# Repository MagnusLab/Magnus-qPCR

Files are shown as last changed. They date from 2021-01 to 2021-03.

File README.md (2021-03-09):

# 
An open, portable and low cost qPCR machine.

## WE ARE ACCEPTING [DONATIONS](https://www.vakinha.com.br/vaquinha/nos-ajude-a-desenvolver-uma-maquina-de-qpcr-a-baixo-custo)!: 

## Specifications*:
* 8 samples
* 1 to 4 channels, you can customize it!
  * FAM/Sybr Green
  * HEX
  * ROX/Cal Red 610
  * Cy5
* MicroSD card slot for data logging
* High Resolution Melting Analysis
* WiFi interface, so you can control and visualize data from a smartphone/PC
* Portable (less than 150 mm in size)
* USB powered (5V 3A power supply)
* CHEAP

**This machine is a work in progress, so the specifications may change and/or be innacurate. Also, don't try to replicate it if you don't know what you're doing, as it probably won't work until we release a stable version.*

## How will it work?
The machine can be roughly separated into 3 parts:

* The main PCB, containing the microcontroller and the heater;
* The PCB of the reading head, containing LEDs and light sensors;
* The optical reading head, which will house lenses, beam splitters, filters, prisms, etc., as well as the stepper motor responsible for positioning this optical assembly above each tube;


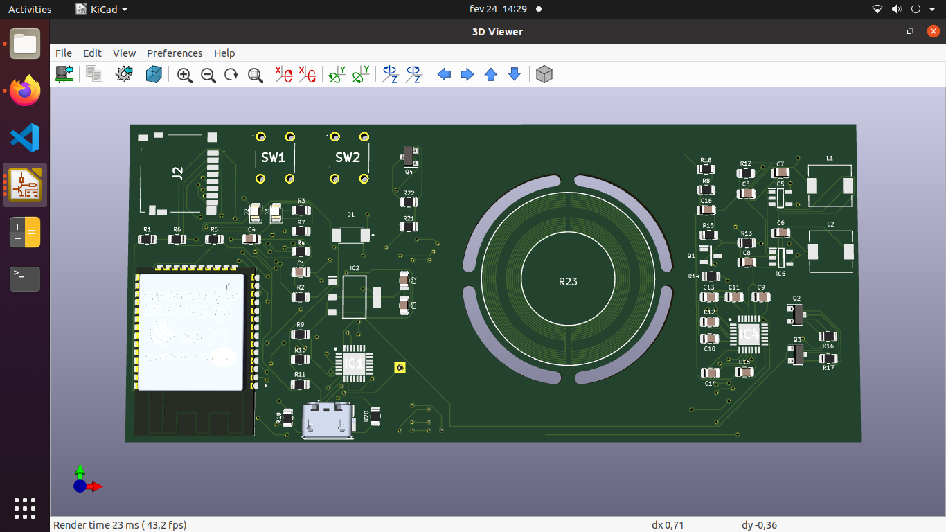
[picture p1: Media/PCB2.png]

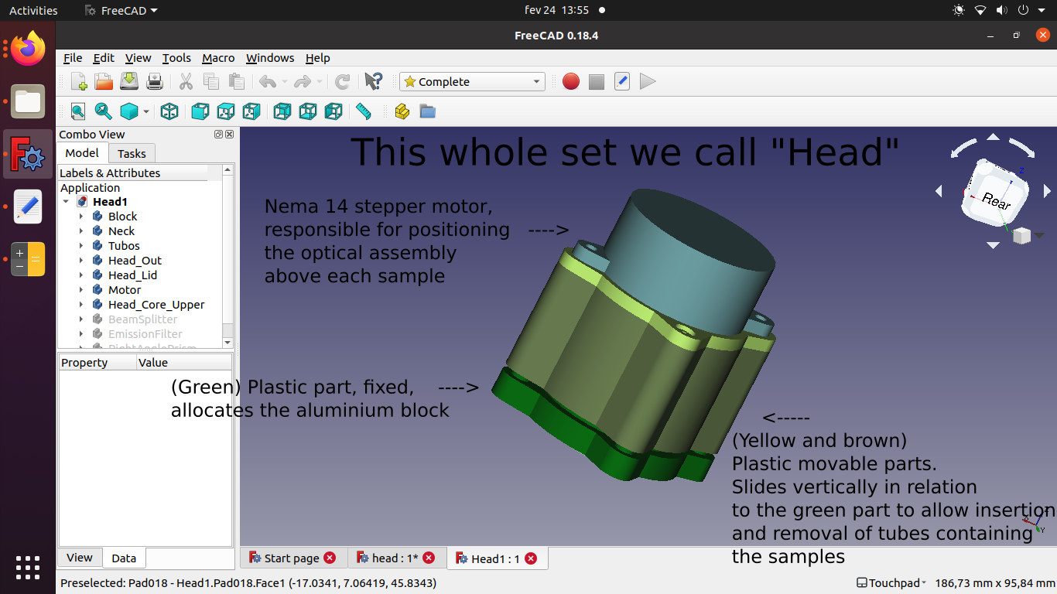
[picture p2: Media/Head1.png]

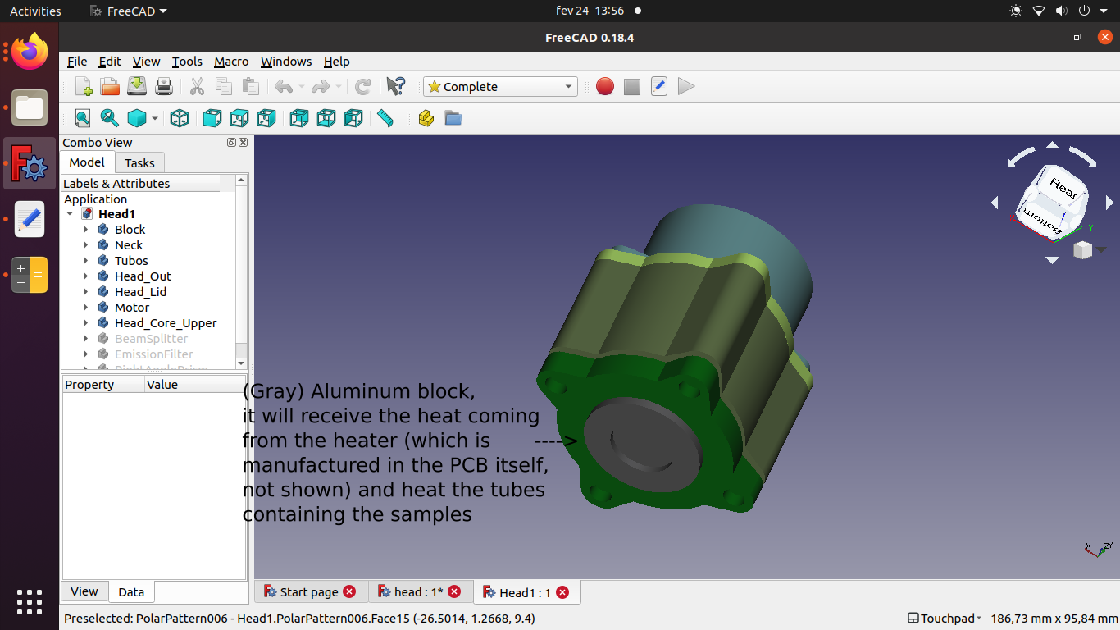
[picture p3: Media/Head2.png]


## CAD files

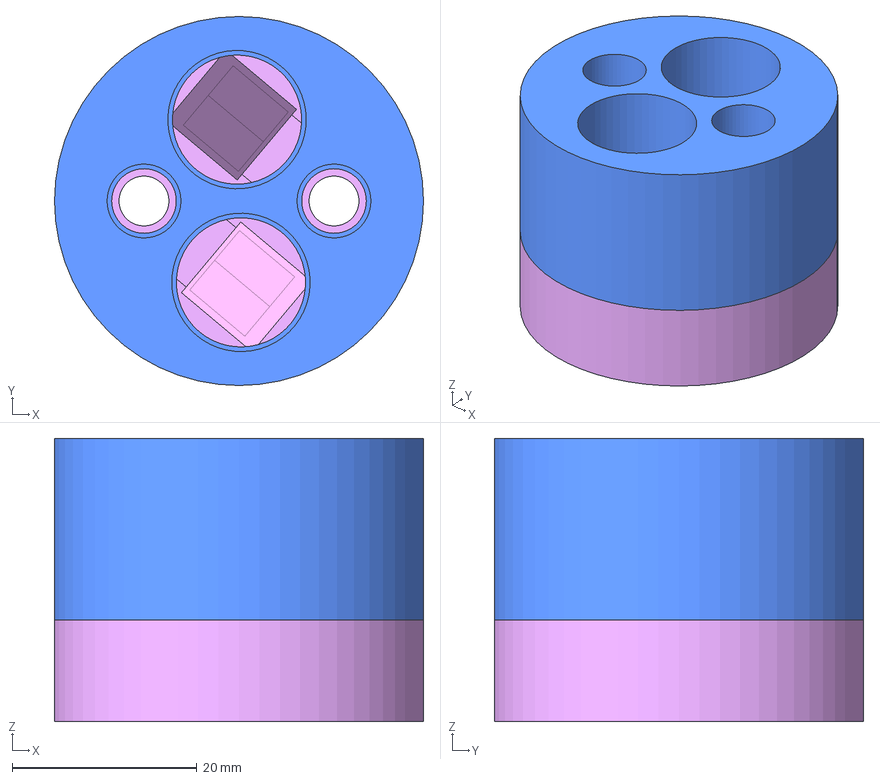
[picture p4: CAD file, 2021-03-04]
Hardware/FreeCAD/head.FCStd
40.0 x 40.0 x 30.7 mm
Head_Core_Bottom
Head_Core_Top

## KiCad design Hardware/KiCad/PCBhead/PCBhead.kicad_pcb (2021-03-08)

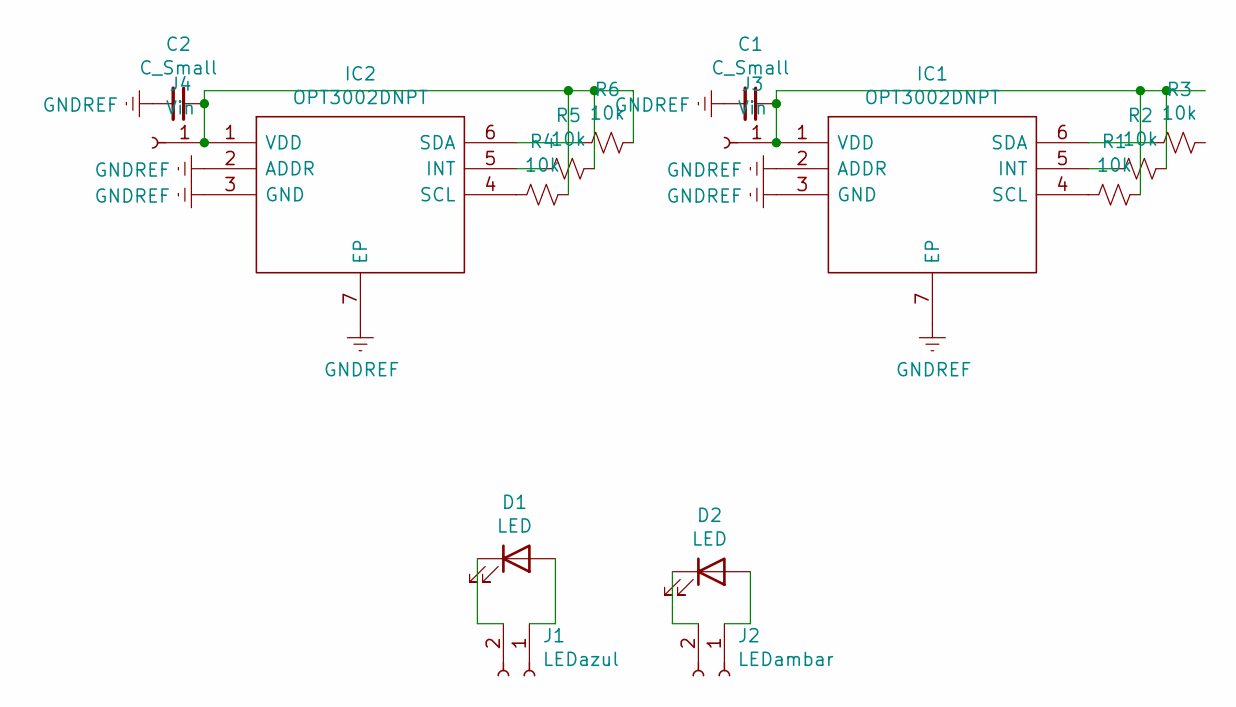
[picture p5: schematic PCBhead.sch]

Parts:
C1, C2: C_Small; C_0805_2012Metric
D1, D2: LED
IC1, IC2: OPT3002DNPT; SON65P200X200X65-7N-D; Mouser Part Number 595-OPT3002DNPT
J1: LEDazul; PinSocket_1x02_P2.54mm_Horizontal
J2: LEDambar; PinSocket_1x02_P2.54mm_Horizontal
J3, J4: Vin; PinSocket_1x01_P2.54mm_Horizontal
R1, R2, R3, R4, R5, R6: 10k; R_0805_2012Metric

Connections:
GNDREF: C1.2, C2.2, IC1.2 (ADDR), IC1.3 (GND), IC1.7 (EP), IC2.2 (ADDR), IC2.3 (GND), IC2.7 (EP)
unnamed: C1.1, IC1.1 (VDD), J3.1, R1.1, R2.1
unnamed: C2.1, IC2.1 (VDD), J4.1, R4.1, R5.1, R6.1
unnamed: D1.1 (K), J1.2
unnamed: D1.2 (A), J1.1
unnamed: D2.1 (K), J2.2
unnamed: D2.2 (A), J2.1
unnamed: IC1.4 (SCL), R1.2
unnamed: IC1.5 (INT), R2.2
unnamed: IC1.6 (SDA), R3.2
unnamed: IC2.4 (SCL), R4.2
unnamed: IC2.5 (INT), R5.2
unnamed: IC2.6 (SDA), R6.2

Board: 2 copper layers, 16 parts (12 on the bottom side), 13 nets, no tracks yet.

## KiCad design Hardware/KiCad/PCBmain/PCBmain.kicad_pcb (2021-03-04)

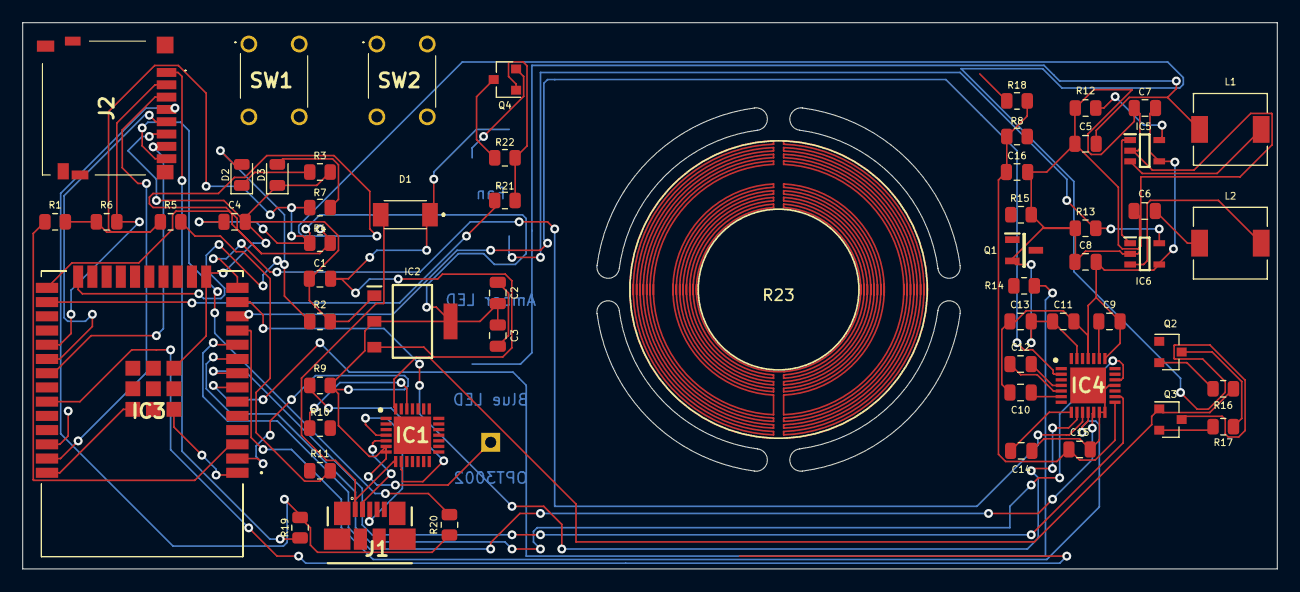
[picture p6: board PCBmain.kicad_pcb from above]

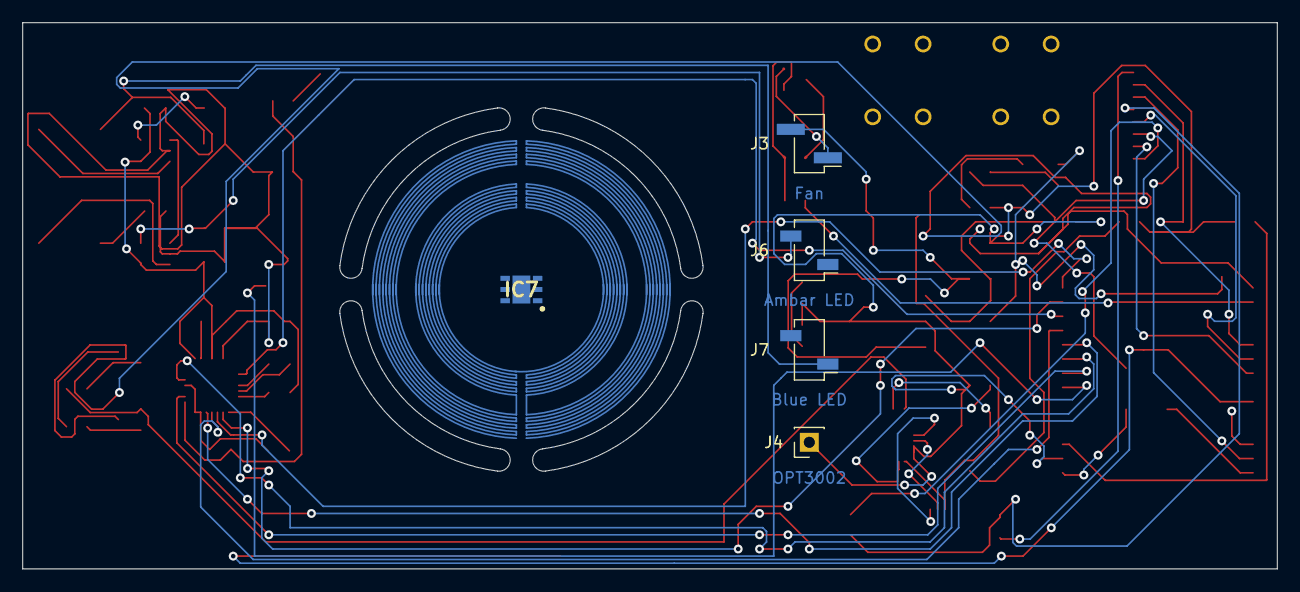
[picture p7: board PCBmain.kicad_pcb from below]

Board: 2 copper layers, 112.0 x 48.8 mm, 63 parts (5 on the bottom side), 53 nets.

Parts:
C1, C3, C5, C6, C7, C8: 10µF; C_0805_2012Metric
C2, C11, C13, C15: 100nF; C_0805_2012Metric
C4: 100µF 6.3V; C_0805_2012Metric
C9: 100µF; C_0805_2012Metric
C10: 22nF 50V; C_0805_2012Metric
C12: 100nF 16V; C_0805_2012Metric
C14: 2.2µF 6.3V; C_0805_2012Metric
C16: 0.1µF; C_0805_2012Metric
D1: D_Schottky_Small; PMEG3050EP115
D2, D3: LED; LED_0805_2012Metric
IC1: CP2102; QFN50P500X500X100-29N-D
IC2: NCP1117ST33T3G; SOT230P700X180-4N
IC3: ESP32-WROOM-32_M103QH3200PH3Q0_; ESP32WROOM32M103QH3200PH3Q0
IC4: TMC2208-LA-T; QFN50P500X500X90-29N-D
IC5, IC6: PAM2804AAB010; SOT95P280X100-5N
IC7: TMP117AIDRVT; SON100P300X300X80-7N-D
J1: 47346-0001
J2: DM3D-SF; DM3DSF
J3: fan; PinHeader_1x02_P2.54mm_Vertical_SMD_Pin1Left
J4: OPT3002; PinSocket_1x01_P2.54mm_Vertical
J6: LEDambar; PinSocket_1x02_P2.54mm_Vertical_SMD_Pin1Left
J7: LEDazul; PinSocket_1x02_P2.54mm_Vertical_SMD_Pin1Left
L1, L2: 4,7µH; L_6.3x6.3_H3
Q1: IRLML6244TRPBF; SOT95P237X112-3N
Q2, Q3: S8050; SOT-23
Q4: Q_NMOS_GDS; SOT-23
R1, R2, R4, R5, R6, R8, R15, R16, R17, R18, R19, R20, R22: 10k; R_0805_2012Metric
R3, R7, R10, R11: 1k; R_0805_2012Metric
R9: 4.7k; R_0805_2012Metric
R12, R13: ?; R_0805_2012Metric
R14, R21: 200; R_0805_2012Metric
R23: Heater; aquecedor
SW1, SW2: SW_Push; TS665CJ

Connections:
/3.3V: J2.4, R19.2, R20.1
/CLK: IC3.30, J2.5
/CMD: IC3.37, J2.3
/D+: IC1.4, J1.3
/D-: IC1.5, J1.2
/DAT0: IC3.31, J2.7
/DIAG: IC3.11, IC4.11
/DIR: IC3.9, IC4.19
/DTR: IC1.28, Q3.1, R16.1
/EN: IC3.3, Q2.1, R1.1
/ENN: IC3.12, IC4.2
/GPIO0: IC3.25, Q3.3, R4.2
/GPIO2: D2.2, IC3.24, R2.1
/GPIO5: IC3.29, J2.2, R6.2
/INDEX: IC3.10, IC4.12
/LEDamar+: C6.2, L2.1
/LEDambar-: IC6.5, J6.2, R13.2
/LEDazul+: C5.2, J7.1, L1.1
/LEDazul-: IC5.5, J7.2, R12.2
/MS1: IC3.13, IC4.9
/MS2: IC3.14, IC4.10
/Mosfet: Q1.3, R23.2
/PWMaquecedor: IC3.7, R14.2
/PWMled: IC3.6, IC5.1, IC6.1
/RTS: IC1.24, Q2.3, R17.1
/SCL: IC3.36, IC7.1, R8.2
/SDA: IC3.33, IC7.6, R18.2
/STEP: IC3.8, IC4.16
/TX0: R5.2, R11.2
/VCC_USB: D1.2, IC1.8, J1.1
/VDD_3.3V: C2.2, C3.1, C4.1, C15.1, C16.1, IC1.6, IC1.7, IC2.2, IC2.4, IC3.2, IC4.15, IC7.5, J4.1, R1.2, R4.1, R5.1, R6.1, R7.1, R8.1, R9.2, R18.1
/Vin: C1.1, C7.2, C8.2, C9.1, C10.2, C11.2, C13.2, D1.1, IC2.3, IC4.22, IC4.25, IC5.4, IC6.4, J3.2, R23.1
/fan: IC3.26, R21.1
/stepperMotor: IC4.1, IC4.21, IC4.24, IC4.26
GNDREF: C1.2, C2.1, C3.2, C4.2, C5.1, C6.1, C7.1, C8.1, C9.2, C11.1, C13.1, C14.1, C15.2, C16.2, D3.1, IC2.1, IC3.1, IC3.15, IC3.38, IC3.39, IC3.40, IC3.41, IC3.42, IC3.43, IC3.44, IC3.45, IC3.46, IC3.47, IC4.3, IC4.13, IC4.14, IC4.18, IC4.23, IC4.27, IC4.29, IC5.2, IC6.2, IC7.2, J1.5, J2.6, Q1.2, Q4.3, R2.2, R3.2, R12.1, R13.1, R15.1, R22.1
unnamed: C10.1, IC4.6
unnamed: C12.1, IC4.5
unnamed: C12.2, IC4.4
unnamed: C14.2, IC4.8
unnamed: D2.1, R3.1
unnamed: D3.2, R7.2
unnamed: IC1.9, R9.1
unnamed: IC1.25, R11.1
unnamed: IC1.26, R10.1
unnamed: IC5.3, L1.2
unnamed: IC6.3, L2.2
unnamed: J2.1, R19.1
unnamed: J2.8, R20.2
unnamed: J3.1, Q4.2
unnamed: Q1.1, R14.1, R15.2
unnamed: Q2.2, R16.2
unnamed: Q3.2, R17.2
unnamed: Q4.1, R21.2, R22.2

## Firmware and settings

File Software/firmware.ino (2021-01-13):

#include <Servo.h>

#include "esp_task_wdt.h"
#include <ArduinoJson.h>
//
#include <stdio.h>
#include <stdlib.h>
#include <SPI.h>
#include <FS.h>
#include "SPIFFS.h"
//
#include <WiFi.h>
#include "time.h"
#include <WiFiClient.h>
#include <WebServer.h>
#include <ESPmDNS.h>

WebServer server(80);
//
const unsigned int pinThermVcc = 25;
const unsigned int pinThermADC = 35;
const unsigned int pinTSL235RVcc = 12;
const unsigned int pinTSL235Rdata = 34;
const unsigned int pinServo = 32;
const unsigned int pinHeater = 33;
const unsigned int pinFan = 13;

const unsigned int ledR = 14;
const unsigned int ledG = 27;
const unsigned int ledB = 26;
const unsigned int led2 = 2;

const unsigned int ThermR0 = 100000;
const int ThermTemp0 = 25;
const unsigned int ThermBeta = 3950;
const unsigned int ThermRSeries = 100000;

const char* ssid     = "Benicio";
const char* password = "989666195";

const char* ntpServer = "pool.ntp.org";
const long  gmtOffset_sec = -3 * 3600;
const int   daylightOffset_sec = 0;

#define FORMAT_SPIFFS_IF_FAILED true

TaskHandle_t Task0;

struct DataLog {
  int tempWell;
  unsigned long time_;
  float data_;
};

void writeFile(fs::FS &fs, const char * path, const char * message);
int readIntFromFile(const char *path);
void appendFile(fs::FS &fs, const char * path, const char * message);
void deleteFile(fs::FS &fs, const char * path);

class CycleStepper {
    const char* _json = "[{\"iterations\":1,\"cycle\":[{\"temp\":95,\"duration\":15,\"fluorRead\":false}]},{\"iterations\":5,\"cycle\":[{\"temp\":95,\"duration\":3,\"fluorRead\":false},{\"temp\":56,\"duration\":30,\"fluorRead\":true}]}]";
    const char* _cycleJson; // = "[{\"iterations\":1,\"cycle\":[{\"temp\":37,\"duration\":60,\"fluorRead\":false},{\"temp\":31,\"duration\":18,\"fluorRead\":true}]},{\"iterations\":1,\"cycle\":[{\"temp\":95,\"duration\":30,\"fluorRead\":false},{\"temp\":60,\"duration\":30,\"fluorRead\":false},{\"iterations\":2,\"cycle\":[{\"temp\":20,\"duration\":10,\"fluorRead\":false},{\"temp\":22,\"duration\":5,\"fluorRead\":false}]},{\"iterations\":2,\"cycle\":[{\"temp\":72,\"duration\":30,\"fluorRead\":true}]}]},{\"iterations\":2,\"cycle\":[{\"temp\":4,\"duration\":0}]}]";
    enum States {ZERO, TEST_END_REACHED, TEMP_OR_HEADER, TEMP, HEADER} state = ZERO;
    static const unsigned int MAX_SIZE_STATES = 16;
    struct StatesVariables {
      int iterations;
      int index;
    } statesVars[MAX_SIZE_STATES];
    int statesVarsCount;
    struct CurrentCycle {
      float temp;
      float duration;
      bool readFluor;
    } currentCycle;

  public:
    void init(const char* cycleJson) {
      Serial.printf("CycleStepper::init started on core %d\n", xPortGetCoreID());
      char *cycleJson_;
      cycleJson_ = (char*)malloc(strlen(cycleJson)+1);
      strncpy(cycleJson_, cycleJson, strlen(cycleJson)+1);
      _cycleJson = (const char*)cycleJson_;
      Serial.printf("Cyclestepper::init, _cycleJson = %s\n", _cycleJson);
    }
    void getCurrentCycle(float* temp, float* duration, bool*readFluor) {
      *temp = currentCycle.temp;
      *duration = currentCycle.duration;
      *readFluor = currentCycle.readFluor;
    }
    bool nextStep() {
      while (true) {
        DynamicJsonDocument doc(ESP.getMaxAllocHeap());
        doc.clear();
        deserializeJson(doc, _json);
        doc.shrinkToFit();
        Serial.printf("Cyclestepper::nextStep, _cycleJson = %s\n", (const char*)_cycleJson);
        JsonObject root_0_cycle_0 = doc[0]["cycle"][0];
        int root_0_cycle_0_temp = root_0_cycle_0["temp"]; // 95
        Serial.printf("root_0_cycle_0_temp = %d\n", root_0_cycle_0_temp);
        
        JsonArray arr = doc.as<JsonArray>();
        JsonArray::iterator it = arr.begin();
        for (int i = 0; i < (statesVarsCount - 1); i++) {
//          Serial.println((char*)(*it));
          for (int j = 0; j < statesVars[i].index; j++) ++it;
          JsonObject obj = (*it); // testar se realmente eh necessario, ja que it eh um ponteiro
          arr = obj["cycle"];
          it = arr.begin();
        }
        for (int i = 0; i < statesVars[statesVarsCount - 1].index; i++) {
          ++it;
        };
        JsonObject obj = (*it);
        Serial.printf("state = %d\n", state);
        switch (state) {
          case ZERO: {            
              for (int i = 0; i < MAX_SIZE_STATES; i++) {
                statesVars[i].index = 0;
                statesVars[i].iterations = 0;
              }
              statesVars[0].iterations = obj["iterations"];
              statesVarsCount = 1;
              state = TEST_END_REACHED;
              break;
            }
          case TEST_END_REACHED: {
              state = TEMP_OR_HEADER;
              if (it == arr.end()) {
                statesVars[statesVarsCount - 1].index = 0;
                if ((statesVarsCount == 1) && statesVars[0].iterations == 1) return false;
                if (statesVars[statesVarsCount - 2].iterations == 1) {
                  statesVars[statesVarsCount - 2].index++;
                  statesVarsCount--;
                } else {
                  statesVars[statesVarsCount - 2].iterations--;
                }

                state = TEST_END_REACHED;
              }
              break;
            }
          case TEMP_OR_HEADER: {
              float temp = obj["temp"];
              float header = obj["iterations"];
              if (temp) {
                state = TEMP;
              } else if (header) {
                state = HEADER;
              }
              break;
            }
          case TEMP: {
              currentCycle.temp = obj["temp"];
              currentCycle.duration = obj["duration"];
              currentCycle.readFluor = obj["fluorRead"];
              statesVars[statesVarsCount - 1].index++;
              state = TEST_END_REACHED;
              Serial.printf("currentCycle:\n\ttemp: %f\n\tduration: %f\n\treadFluor: %s\n\n", currentCycle.temp, currentCycle.duration, currentCycle.readFluor ? "true" : "false");
              return true;
            }
          case HEADER: {
              statesVars[statesVarsCount - 1].iterations = obj["iterations"];
              statesVars[statesVarsCount].index = 0;
              statesVarsCount++;
              state = TEST_END_REACHED;
              break;
            }
        }
      }
    }
    void finalize() {
      free((void*)_cycleJson);
    }
};
class Thermistor {
  public:
    unsigned int _pinADC;
    unsigned int _pinVcc;
    unsigned int _R0;
    float _temp0;
    unsigned int _beta;
    unsigned int _RSeries;
    void init(unsigned int Vcc, unsigned int ADC, unsigned int R0, float temp0, unsigned int beta, unsigned int RSeries) {
      _pinADC = ADC;
      _pinVcc = Vcc;
      _R0 = R0;
      _temp0 = temp0;
      _beta = beta;
      _RSeries = RSeries;
      pinMode(_pinADC, INPUT);
      pinMode(_pinVcc, OUTPUT);

    }
    float readTemperature(unsigned int counts) {
      unsigned int sumReadings = 0;
      digitalWrite(_pinVcc, HIGH);
      float temp = 0;
      for (unsigned int i = 0; i < counts; i++) {
        do
        {
          temp = analogRead(_pinADC);
        } while (!temp);
        sumReadings += temp;
      }
      digitalWrite(_pinVcc, LOW);
      temp = sumReadings / counts;
      temp = 4095 * _RSeries / temp - _RSeries;
      temp /= _R0;
      temp = log(temp);
      temp /= _beta;
      temp += 1 / (_temp0 + 273.15);
      temp = 1 / temp;
      temp -= 273.15;
      return temp;
    }
};
class TSL235R {
  public:
    unsigned int _pinVcc;
    unsigned int _pinData;
    unsigned long _nPulses;

    void init(unsigned int Vcc, unsigned int datap, unsigned long nPulses) {
      _pinVcc = Vcc;
      _pinData = datap;
      _nPulses = nPulses;
      pinMode(_pinVcc, OUTPUT);
      pinMode(_pinData, INPUT);

    }
    float readLight() {
      digitalWrite(_pinVcc, HIGH);
      unsigned long counts = 0;
      unsigned long startTime = 0;
      unsigned long endTime = 0;
      noInterrupts();
      bool state = digitalRead(_pinData);
      bool oldState = state;
      while (counts <= _nPulses) {
        state = digitalRead(_pinData);
        if (state != oldState) {
          oldState = state;
          if (state) {
            if (!counts) startTime = micros();
            counts++;
          }
        }
      }
      endTime = micros();
      interrupts();
      unsigned long interval = endTime - startTime; // What if endTime < startTime?
      double freq = 10000000 * counts / interval;
      return freq;
    }
};
class PID {
    float _error = 0, _integral = 0, _derivative = 0;
    float _kP = 30000, _kI = 0, _kD = 1000;
    float _setpoint = 0;
    unsigned long _lastUpdate = 0;
    int _lowerLimit = 0;
    int _upperLimit = 65535;

  public:
    void setPID(float kP, float kI, float kD) {
      _kP = kP;
      _kI = kI;
      _kP = kP;
    }
    void setSetpoint(float setpoint) {
      _setpoint = setpoint;
    }
    float getSetpoint() {
      return _setpoint;
    }
    void setLimits(int lower, int upper) {
      _lowerLimit = lower;
      _upperLimit = upper;
    }
    int output(int temp) {
      float newError = _setpoint - temp;
      if (_lastUpdate) {
        unsigned long dt = millis() - _lastUpdate;
        _integral += newError * dt;
        if (_integral >= _upperLimit)
          _integral = _upperLimit;
        _derivative = (newError - _error) / dt;
      }
      float P = _kP * newError;
      float I = _kI * _integral;
      float D = _kD * _derivative;
      float output = P + I + D;
      if (output <= _lowerLimit)
        output = _lowerLimit;
      if (output >= _upperLimit)
        output = _upperLimit;
      _error = newError;
      _lastUpdate = millis();
      return output;
    }
};
class DBase {
    void displayFreeHeap() {
       Serial.printf("Heap size: %d\tFree Heap: %d\tMin Free Heap: %d\tMax Alloc Heap: %d\n", ESP.getHeapSize(), heap_caps_get_free_size(MALLOC_CAP_8BIT), heap_caps_get_minimum_free_size(MALLOC_CAP_8BIT), heap_caps_get_largest_free_block(MALLOC_CAP_8BIT));
    }
/*    void createTables() {
      char* sql;
      sql = "CREATE TABLE IF NOT EXISTS logs (name, cycleID, creationDate)";
      db_exec(sql, NULL, 0);
      sql = "CREATE TABLE IF NOT EXISTS logsWells (logID, name, well)";
      db_exec(sql, NULL, 0);
      sql = "CREATE TABLE IF NOT EXISTS logsData (logID, tempWell, time, data)";
      db_exec(sql, NULL, 0);
      sql = "CREATE TABLE IF NOT EXISTS cycles (name, description, creationDate, cycle)";
      db_exec(sql, NULL, 0);
      return;
    }*/

  public:
    DBase() {
      Serial.print(F("\nDB started on core "));
      Serial.println(xPortGetCoreID());
      
      if (!SPIFFS.begin(FORMAT_SPIFFS_IF_FAILED)) {
        Serial.println(F("Failed to mount file system"));
        return;
      }
      // list SPIFFS contents
      File root = SPIFFS.open("/");
      if (!root) {
        Serial.println(F("- failed to open directory"));
        return;
      }
      if (!root.isDirectory()) {
        Serial.println(F(" - not a directory"));
        return;
      }
    }
    int addLog(const char* logName, int cycleID, unsigned int wellsCount, char* wellsNames[], int wellsNumbers[]) {
      Serial.printf("\naddLog started on core %d\n", xPortGetCoreID());
      int lastIndex = readIntFromFile("/logs/lastIndex");
      if(lastIndex == -1) {
        Serial.printf("Error reading /logs/lastIndex\n");
        return -1;
      }
      char path[25];
      snprintf(path, sizeof(path), "/logs/%d.head", lastIndex);
      char dat[200];
      snprintf(dat, sizeof(dat), "%s,%d,%d\n", logName, cycleID, wellsCount); // INSERIR TB A DATA DE CRIACAO
      writeFile(SPIFFS, path, dat);
      for (int i = 0; i < wellsCount; i++) {
        snprintf(dat, sizeof(dat), "%s,%d\n", wellsNames[i], wellsNumbers[i]);
        appendFile(SPIFFS, path, dat);
      }
      snprintf(dat, sizeof(dat), "%d", lastIndex+1);
      writeFile(SPIFFS, "/logs/lastIndex", dat);
      Serial.printf("log created succesfully!\n");
      displayFreeHeap();
      return lastIndex;
    }
    void addDatapoints(int logID, struct DataLog *datalog) {
      Serial.printf("\naddDatapoints started on core %d\n", xPortGetCoreID());

      char path[25];
      snprintf(path, sizeof(path), "/logs/%d.data", logID);
      char dat[200];
      snprintf(dat, sizeof(dat), "%d,%d,%lu,%f\n", logID, datalog->tempWell, datalog->time_, datalog->data_);
      appendFile(SPIFFS, path, dat);
      displayFreeHeap();
    }
    void addCycle(char* name_, char* description, char* cycle) {
      Serial.printf("\naddCycle started on core %d\n", xPortGetCoreID());

      int lastIndex = readIntFromFile("/cycles/lastIndex");
      if(lastIndex == -1) {
        Serial.print(F("Error reading int from file\n"));
        return;
      }
      char path[25];
      snprintf(path, sizeof(path), "/cycles/%d.head", lastIndex);
      char dat[200];
      snprintf(dat, sizeof(dat), "%s,%s", name_, description); // INSERIR TB A DATA DE CRIACAO
      writeFile(SPIFFS, path, dat);

      snprintf(path, sizeof(path), "/cycles/%d.json", lastIndex);
      writeFile(SPIFFS, path, cycle);

      snprintf(dat, sizeof(dat), "%d", lastIndex+1);
      writeFile(SPIFFS, "/cycles/lastIndex", dat);
      server.send(200, "text/plain", "Inserido");
      Serial.printf("cycle inserted succesfully!\n");
      displayFreeHeap();
    }
    bool getCyclesHeads(unsigned int idMin, unsigned int idMax) {
      int lastIndex = readIntFromFile("/cycles/lastIndex");
      if(lastIndex == -1) {
        Serial.print(F("Error reading int from file\n"));
        return false;
      }
      int realIDMax = (idMax < lastIndex) ? idMax : lastIndex;
      char path[25];
      server.setContentLength(CONTENT_LENGTH_UNKNOWN);
      server.send (200, "text/plain", "");
      for (int i = idMin; i < realIDMax; i++) {
        snprintf(path, sizeof(path), "/cycles/%d.head", i);
        File file = SPIFFS.open(path);
        if(!file){
            Serial.println("Failed to open file for reading");
            return false;
        }
        while(file.available()){
            server.sendContent(file.readString());
            server.sendContent("\n");
        }
        file.close();
      }
      server.sendContent("");
      Serial.println("Terminou a getCyclesHeads");
      displayFreeHeap();
      return true;
    }
    bool getCycleBody(unsigned int id, char** cycle) {
      Serial.print(F("getCycleBody\n"));
      char path[25];
      snprintf(path, sizeof(path), "/cycles/%d.json", id);
      
      if(!SPIFFS.exists(path)) {
        Serial.print(F("Cycle not found!\n"));
        return false;
      }
      File file = SPIFFS.open(path);
      if(!file){
          Serial.println("Failed to open file for reading");
          return false;
      }
      *cycle = (char*)malloc(file.size() + 1);
      strncpy(*cycle, file.readString().c_str(), file.size() + 1);
      file.close();
      Serial.printf("getCycleBody, cycle = %s\n", *cycle);
      displayFreeHeap();
      return true;
    }
    void getLogsHeads(unsigned int idMin, unsigned int idMax) {
      int lastIndex = readIntFromFile("/cycles/lastIndex");
      if(lastIndex == -1) {
        Serial.print(F("Error reading int from file\n"));
        return;
      }
      int realIDMax = (idMax < lastIndex) ? idMax : lastIndex;
      char path[25];
      server.setContentLength(CONTENT_LENGTH_UNKNOWN);
      server.send (200, "text/plain", "");
      for (int i = idMin; i < realIDMax; i++) {
        snprintf(path, sizeof(path), "/logs/%d.head", i);
        File file = SPIFFS.open(path);
        if(!file){
            Serial.println("Failed to open file for reading");
            return;
        }
        while(file.available()){
            server.sendContent(file.readString());
        }
        file.close();
      }
      server.sendContent("");
      Serial.println("Terminou a getLogsHeads");
      displayFreeHeap();
    }
    void getLogData(unsigned int id) {
      char path[30];
      snprintf(path, sizeof(path), "/%d.dat", id);
      if (!SPIFFS.exists(path)) {
        Serial.println("Log not found!");
        server.send(200, "text/plain", "Log not found!");
        return;
      }
      File file = SPIFFS.open(path, "r");
      server.streamFile(file, "text/plain");
//      readFile(SPIFFS, path);
      file.close();
      displayFreeHeap();
      return;
    
    }
};
class ThermalCycler {
    Thermistor thermSensor;
    TSL235R lightSensor;
    Servo servo;
    DBase* _db;
    PID pid;
    CycleStepper cycleStepper;
    int* _wells;
    int _wellsCount;
    int _logID;
    char _logPath[30];
  public:
    bool activeFlag = false;
    bool init(int cycleID, char runName[], DBase* db, int* wells, char *wellsNames[], int wellsCount) {
      Serial.printf("ThermalCycler::init started on core %d\n", xPortGetCoreID());
      if(!SPIFFS.begin()){
        Serial.println("Card Mount Failed");
        return false;
      }
      char* cycle = NULL;
      if (!(_db->getCycleBody(cycleID, &cycle))) {
        return false;
      }
      cycleStepper.init((const char*)cycle);
      free(cycle);
      _logID = ((DBase*)db)->addLog(runName, cycleID, wellsCount, wellsNames, wells);
      snprintf(_logPath, sizeof(_logPath), "/%d.dat", _logID);
      deleteFile(SPIFFS, _logPath);
      _db = db;
      _wells = (int*)malloc(wellsCount*sizeof(int));
      if (_wells == NULL) {
        Serial.printf("Nao mallocou o _wells!\n");
        return false;
      }
      for (int i = 0; i < wellsCount; i++) {
        _wells[i] = wells[i];
      }
      _wellsCount = wellsCount;
      servo.attach(pinServo, 0/*Servo::CHANNEL_NOT_ATTACHED*/, 0, 180);
      ledcSetup(1, 5000, 16);
      ledcAttachPin(pinHeater, 1);
      thermSensor.init(pinThermVcc, pinThermADC, ThermR0, ThermTemp0, ThermBeta, ThermRSeries);
      lightSensor.init(pinTSL235RVcc, pinTSL235Rdata, 1000);
      return true;
    }
    void runPCR() {
      Serial.printf("ThermalCycler::runPCR started on core %d\n", xPortGetCoreID());
      char datalog[100];
      activeFlag = true;
      float thermReading = thermSensor.readTemperature(100);
      pid.setSetpoint(thermReading);
      unsigned long delayServo = millis();
      unsigned long timeTotal = millis();
      unsigned long timeStartRun = millis();
      digitalWrite(led2, HIGH);
      while (cycleStepper.nextStep()) {
        float temp, duration;
        bool readFluor = false;
        cycleStepper.getCurrentCycle(&temp, &duration, &readFluor);
        pid.setSetpoint(temp);
        bool rising = ((thermReading <= temp) ? true : false);
        Serial.print("rising = ");
        Serial.println(rising);
        bool reached = false;
        unsigned long timeStartStage = millis();
        unsigned long timeStartServo = millis();
        int iWell = 0;
        bool waitingServo = false;
        while (true) {
          delay(200); // TESTE
          thermReading = thermSensor.readTemperature(1000);
          timeTotal = millis();
          snprintf(datalog, sizeof(datalog), "0,%lu,%f\n", (timeTotal - timeStartRun), thermReading);
          appendFile(SPIFFS, _logPath, datalog);
          int currentPid = pid.output(thermReading);
          ledcWrite(1, currentPid);
          Serial.printf("time = %lu\ttemp = %f\tcurrentPID = %d\tsetpoint = %f\tduration = %f\n", (timeTotal - timeStartRun), thermReading, currentPid, temp, duration);
          if (!currentPid) digitalWrite(pinFan, HIGH);
          if (reached) {
            if ((millis() - timeStartStage) >= (duration * 1000)) {
              if (!readFluor) break;
              // Reading fluorescence:
              if (!waitingServo) {
                timeStartServo = millis();
                servo.write((_wells[iWell]-1)*72); // 72 = 360 / 5
                Serial.printf("servo position: %d\n", (_wells[iWell]-1)*72);
                waitingServo = true;
              }
              if ((millis() - timeStartServo) < 500) continue; // 500 is a delay to wait the servo to reach its position
              digitalWrite(ledB, HIGH);
              float fluorReading = lightSensor.readLight();
              digitalWrite(ledB, LOW);
              Serial.printf("time = %lu\tfluor = %f\n", (millis() - timeStartRun), fluorReading);
              snprintf(datalog, sizeof(datalog), "%d,%lu,%f\n", _wells[iWell], (millis() - timeStartRun), fluorReading);
              appendFile(SPIFFS, _logPath, datalog);
              waitingServo = false;
              iWell++;
              if (iWell >= _wellsCount) break;
            }
            continue;
          }
          if (rising && (thermReading < temp)) continue;
          if ((!rising) && (thermReading > temp)) continue;
          reached = true;
          timeStartStage = millis();
        }
      }
      activeFlag = false;
      digitalWrite(led2, LOW);
      free(_wells);
      cycleStepper.finalize();
      Serial.println("Encerrando TaskThermalCycler...");
      vTaskDelete(NULL);
    }
};

ThermalCycler thermalCycler;
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
void loop() { 
  server.handleClient();
}

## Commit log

2021-03-04 opticalBench pic and mechanical parts
    [head.FCStd]
2021-03-04 Adicionando projeto do KiCad
    [PCBhead.kicad_pcb, PCBhead.sch, PCBmain.kicad_pcb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]
2021-03-08 head update
    [PCBhead.kicad_pcb, PCBhead.sch]
